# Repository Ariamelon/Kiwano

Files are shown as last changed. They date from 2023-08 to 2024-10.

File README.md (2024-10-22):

# Kiwano
Ring rotary encoder and PMW3360/Cirque [VIK](https://github.com/sadekbaroudi/vik) module with RGB backlight.

## Disclaimer
This board is licensed under CERN-OHL-S-2.0.

## Key Features
* PER56 rotary ring encoder.
* Illuminated RGB ring.
* Cirque trackpad support in the middle of the PER56.
* PMW3360 and 34mm trackball support in the middle of the PER56, utilizing 7.5mm BTUs (e.g. Veichu VCN310 7.5mm).
* Trackball has two styles: illuminated outer ring, and illuminated trackball.

## VIK module certification card

| Category | Classification | Response |
| --- | --- | --- |
| FPC connector | Required | :heavy_check_mark: |
| Breakout pins | Recommended | :x: |
| Uses: SPI | Optional | :heavy_check_mark: |
| SPI used for SPI only | Strongly recommended | :heavy_check_mark: |
| Uses: I2C | Optional | :heavy_check_mark: |
| I2C used for I2C only | Strongly Recommended | :heavy_check_mark: |
| I2C pull ups | Required | :heavy_check_mark: |
| Uses: RGB | Optional | :heavy_check_mark: |
| Uses: Extra GPIO 1 | Optional | :heavy_check_mark: |
| Uses: Extra GPIO 2 | Optional | :heavy_check_mark: |
| Standard PCB Size/Mount | Strongly Recommended | Large |

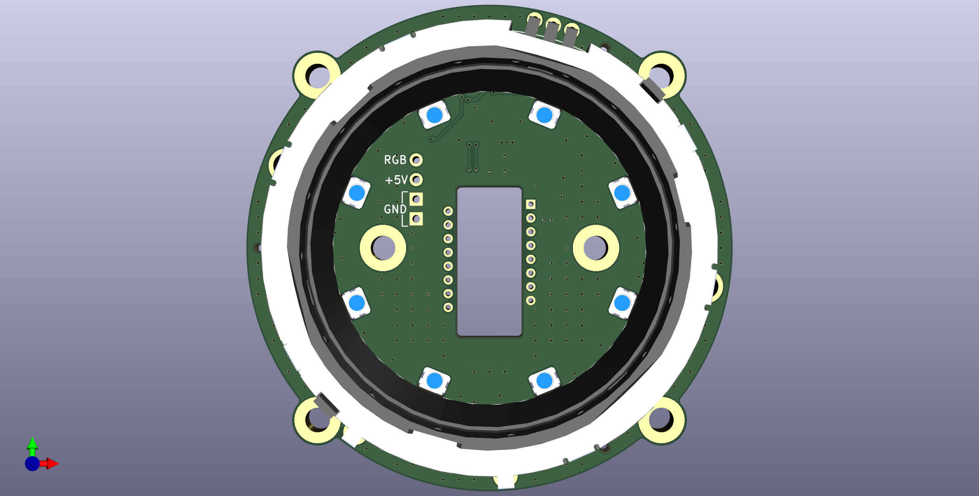
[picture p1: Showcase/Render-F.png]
Render

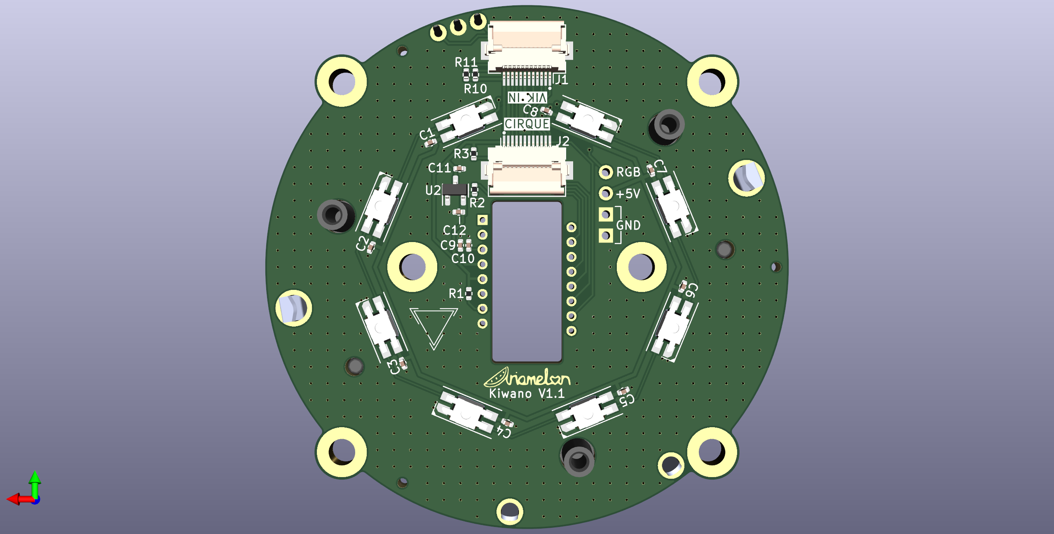
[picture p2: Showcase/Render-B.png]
Render


## Changelog
* 22/10/2024: CERN-OHL-S-2.0 license added.
* 14/10/2023: V1.1 update. Changed LDO to XC6206P202MR. Removed RC filter and pullup from encoder pins.
* 18/09/2023: Fixed .gitignore file. Increased tolerances of PER-56 base mount.
* 28/08/2023: Unified component libraries into one big library. Fixed 3DP files.
* 04/08/2023: Updated SK6812 MINI-E and switch footprints. Changed VIK FFC to FH12. Stitched ground planes together. Fixed VIK footprint. Moved production files to easier to access location.
* 02/08/2023: Fixed 3DP files.
* 01/08/2023: Files for trackpad mount and knob moved here from [Honeydew](https://github.com/Ariamelon/Honeydew/). Added trackball mount STEP files, using 7.5mm BTUs.
* 30/07/2023: Updated BOM.
* 29/07/2023: Added VIK size row to certification card.
* 28/07/2023: Initial commit.

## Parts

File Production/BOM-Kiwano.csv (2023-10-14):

Comment | Designator | Footprint | LCSC
4u7 | C11,C12,C9 | C_0402_1005Metric | C23733
39 | R2 | R_0402_1005Metric | C25164
10k | R1,R3 | R_0402_1005Metric | C25744
4k7 | R10,R11 | R_0402_1005Metric | C25900
XC6206P202MR | U2 | SOT-23-3 | C2891260
100n | C1,C10,C2,C3,C4,C5,C6,C7,C8 | C_0402_1005Metric | C307331
PER56 | SW1 | RotaryEncoder_Bourns_PER561-P115-N0015 | C470483
SK6812MINI-E | D1,D2,D3,D4,D5,D6,D7,D8 | LED_OPSCO_SK6812MINI-E | C524051
VIK Module | J1,J2 | VIK_Module_Horizontal | C88360
PMW3360DM-T2QU_1 | U1 | PixArt_PMW3360DM-T2QU

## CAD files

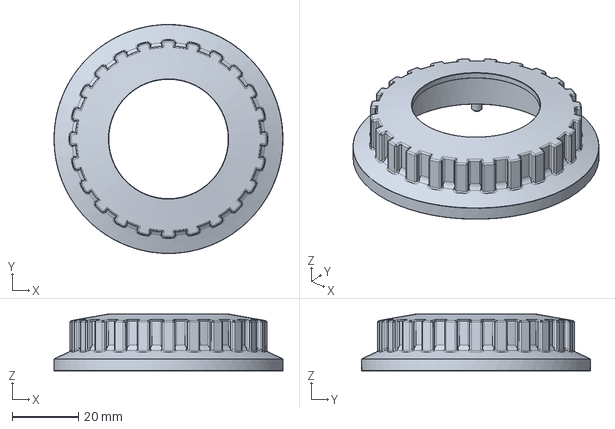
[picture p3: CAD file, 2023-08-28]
3DP/Knob Full.step
69.0 x 69.0 x 17.2 mm

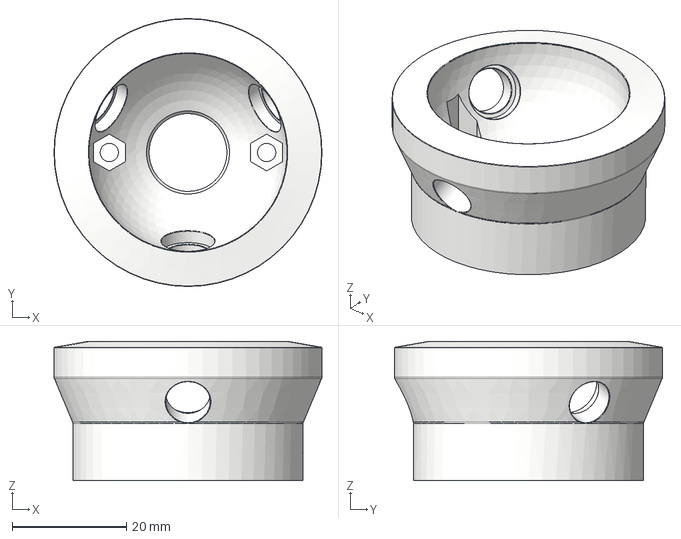
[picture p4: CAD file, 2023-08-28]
3DP/Trackball Mount Full.step
47.0 x 47.0 x 24.4 mm

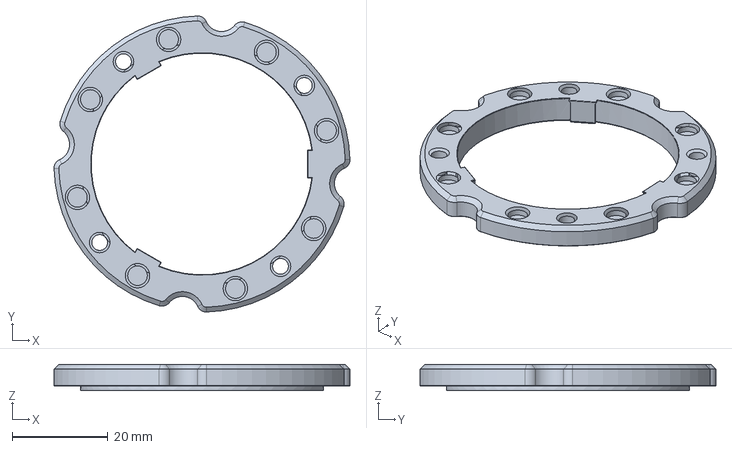
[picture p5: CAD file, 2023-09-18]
3DP/Knob Base.step
62.0 x 62.0 x 5.49 mm

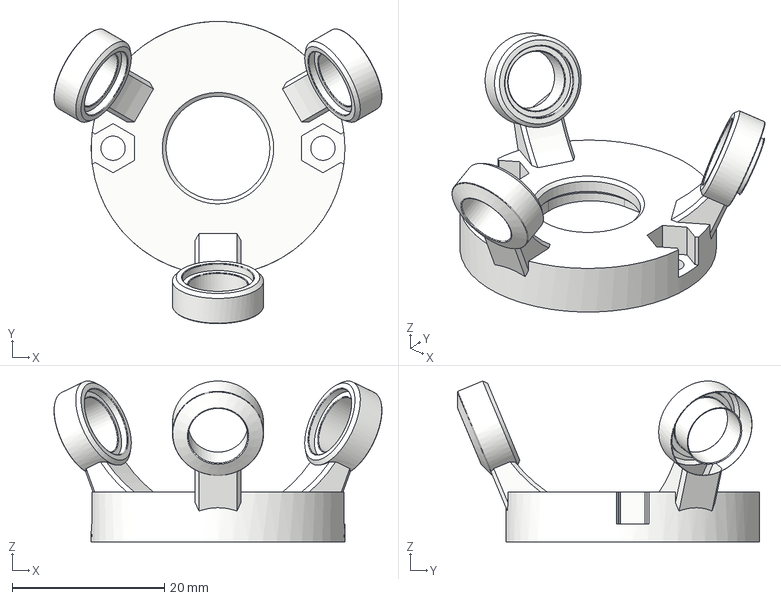
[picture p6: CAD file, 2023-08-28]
3DP/Trackball Mount Low Profile.step
43.1 x 39.7 x 21.2 mm

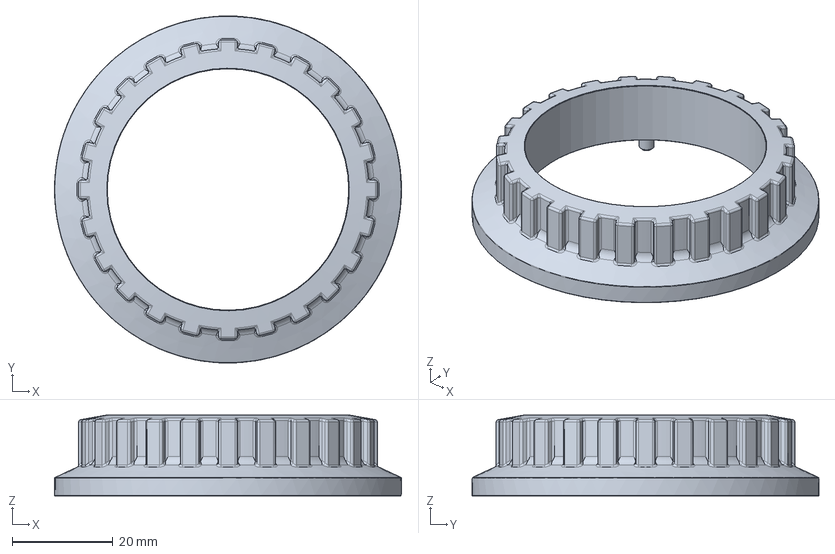
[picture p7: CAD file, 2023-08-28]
3DP/Knob Low Profile.step
69.0 x 69.0 x 16.1 mm

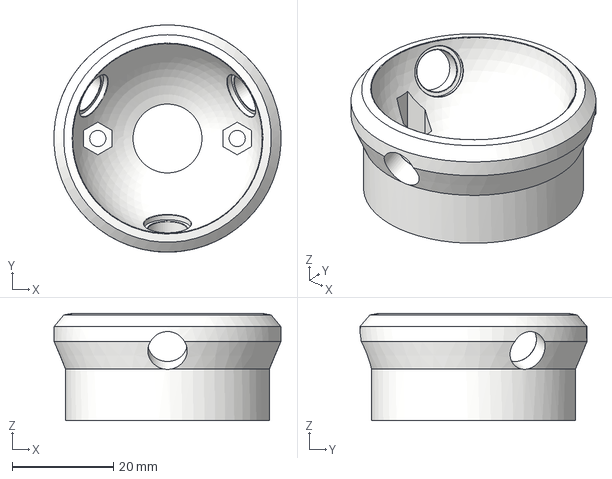
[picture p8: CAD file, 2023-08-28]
3DP/Trackball Mount Semi.step
44.9 x 45.0 x 21.2 mm

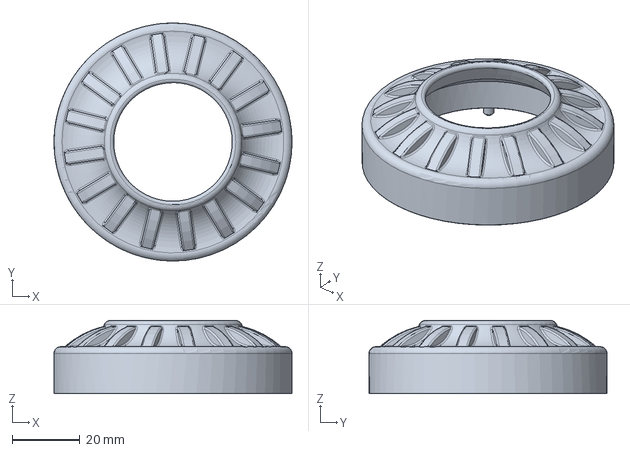
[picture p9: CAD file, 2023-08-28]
3DP/Knob Ribbed.step
70.0 x 70.0 x 21.5 mm

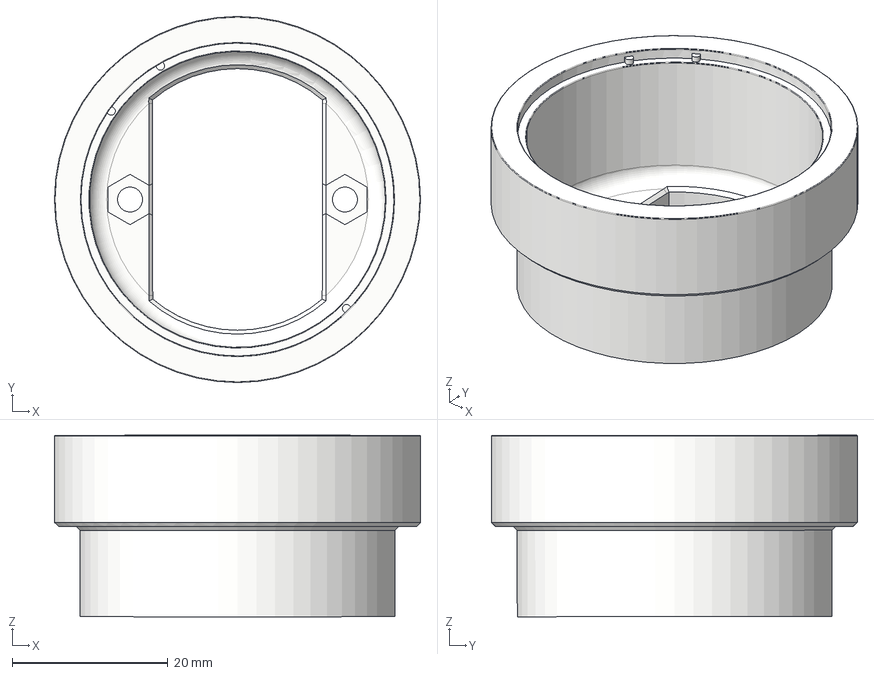
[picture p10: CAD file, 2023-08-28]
3DP/Trackpad Mount.step
47.0 x 47.0 x 23.3 mm

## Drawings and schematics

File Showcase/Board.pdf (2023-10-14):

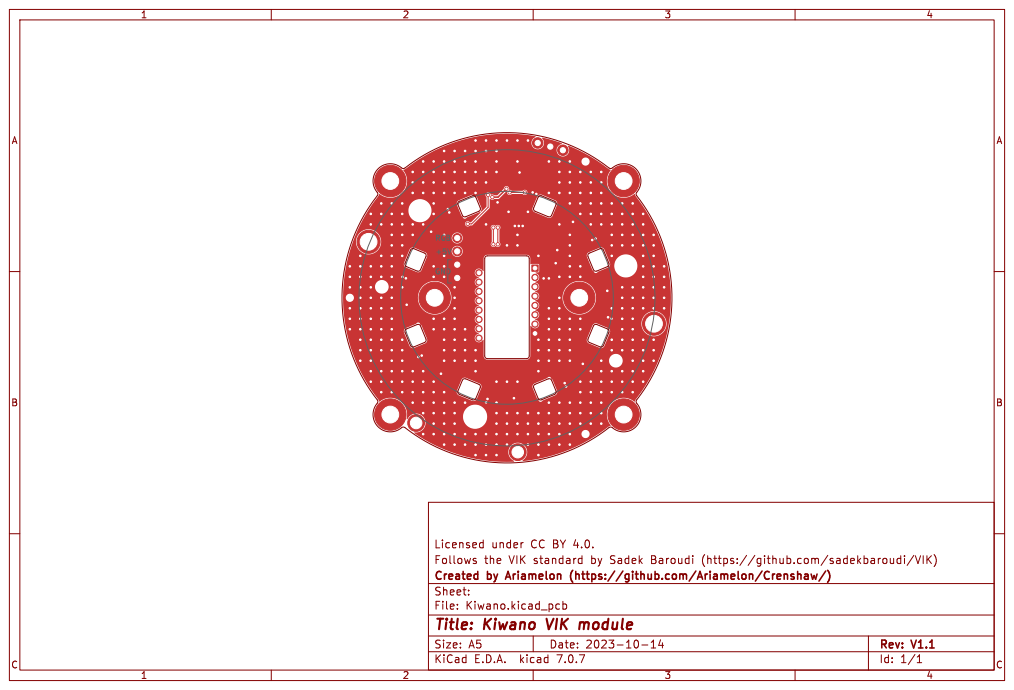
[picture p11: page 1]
GND; +5V RGB 1; BC Date: 2023-10-14 KiCad; kicad; 7.0.7 Size: A5; Rev: V1.1; File:; Kiwano.kicad_pcb Sheet: Created; by Ariamelon; (https://github.com/Ariamelon/Crenshaw/) Follows the VIK standard; by Sadek; Baroudi; (https://github.com/sadekbaroudi/VIK) Licensed; under CC

Id: 1/1 Title: Kiwano VIK module

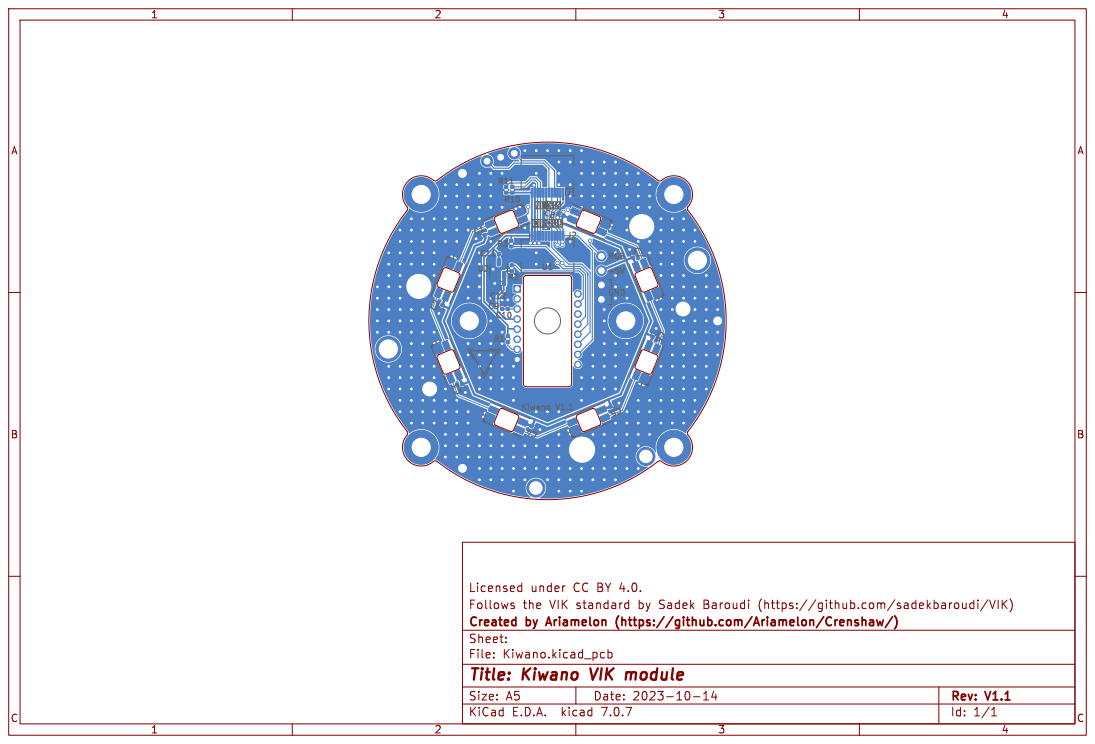
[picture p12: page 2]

Id: 1/1 Title: Kiwano VIK module

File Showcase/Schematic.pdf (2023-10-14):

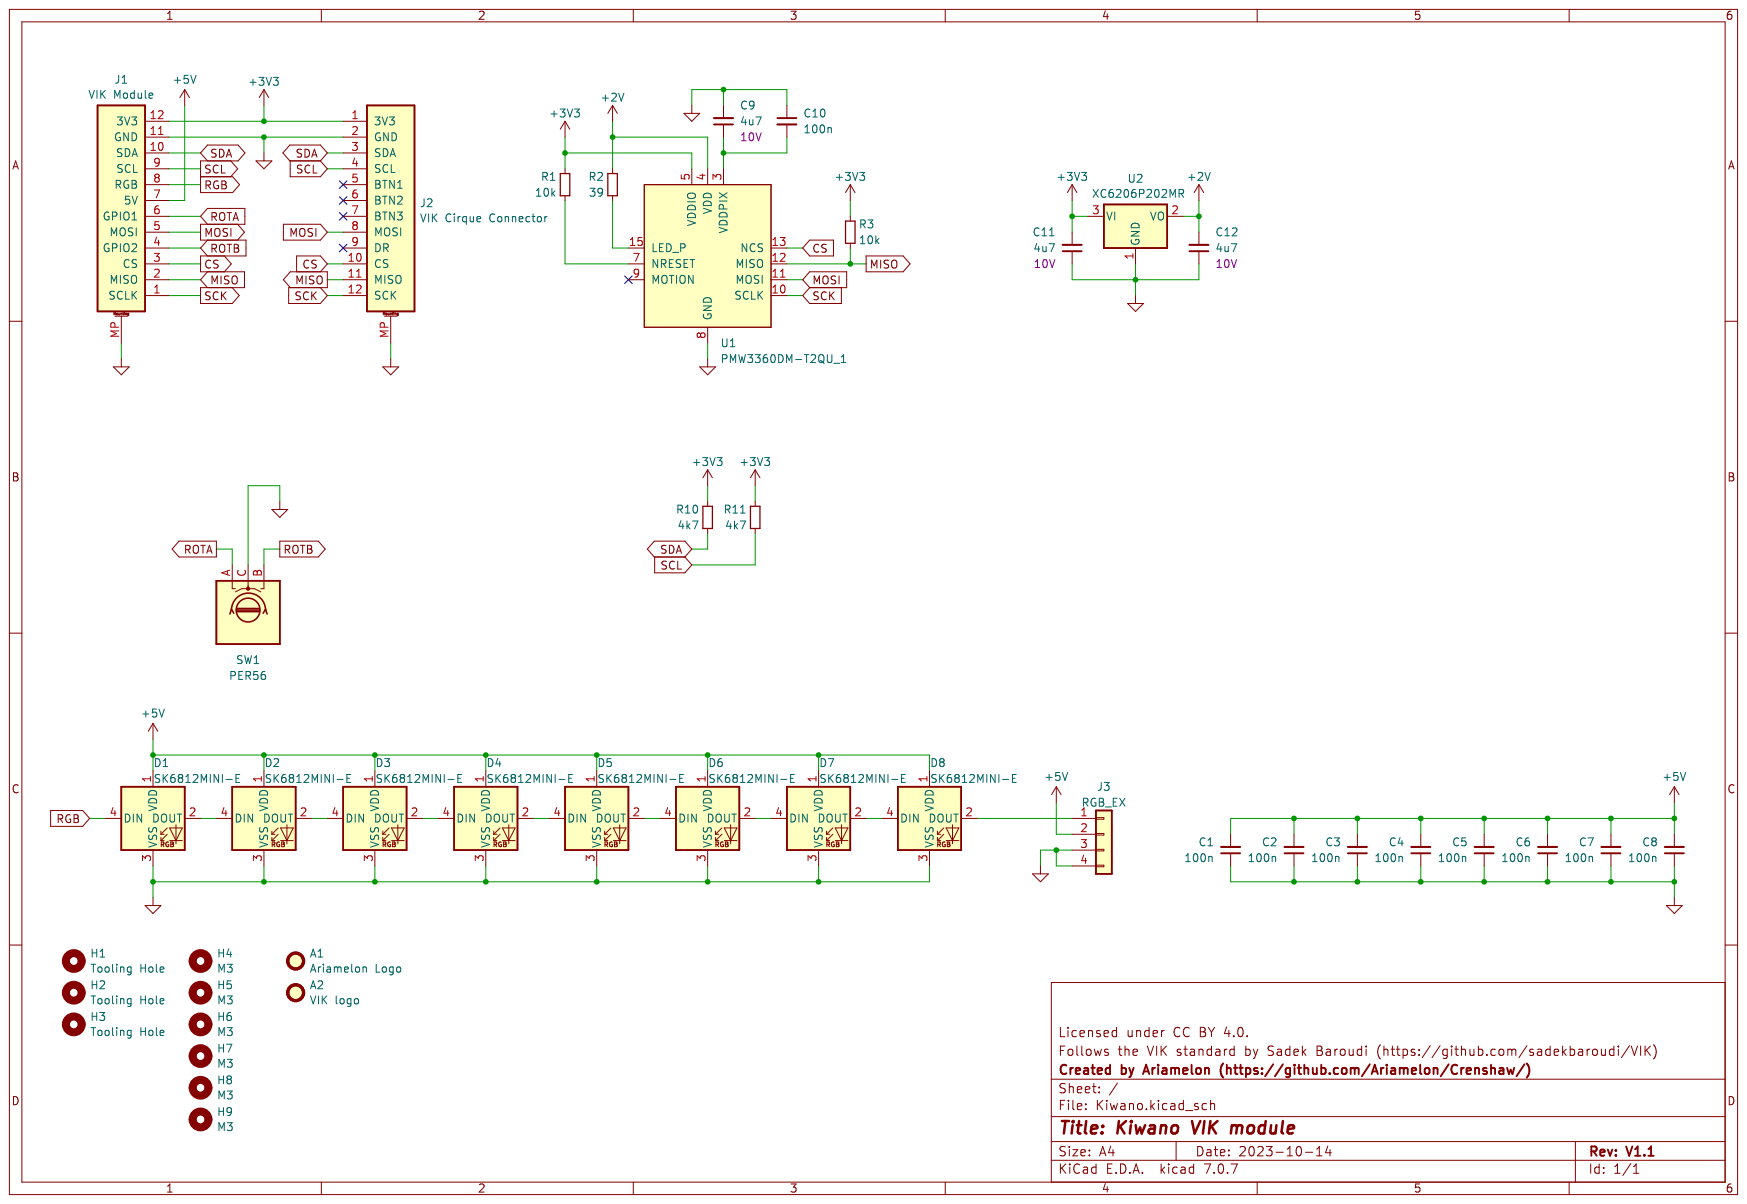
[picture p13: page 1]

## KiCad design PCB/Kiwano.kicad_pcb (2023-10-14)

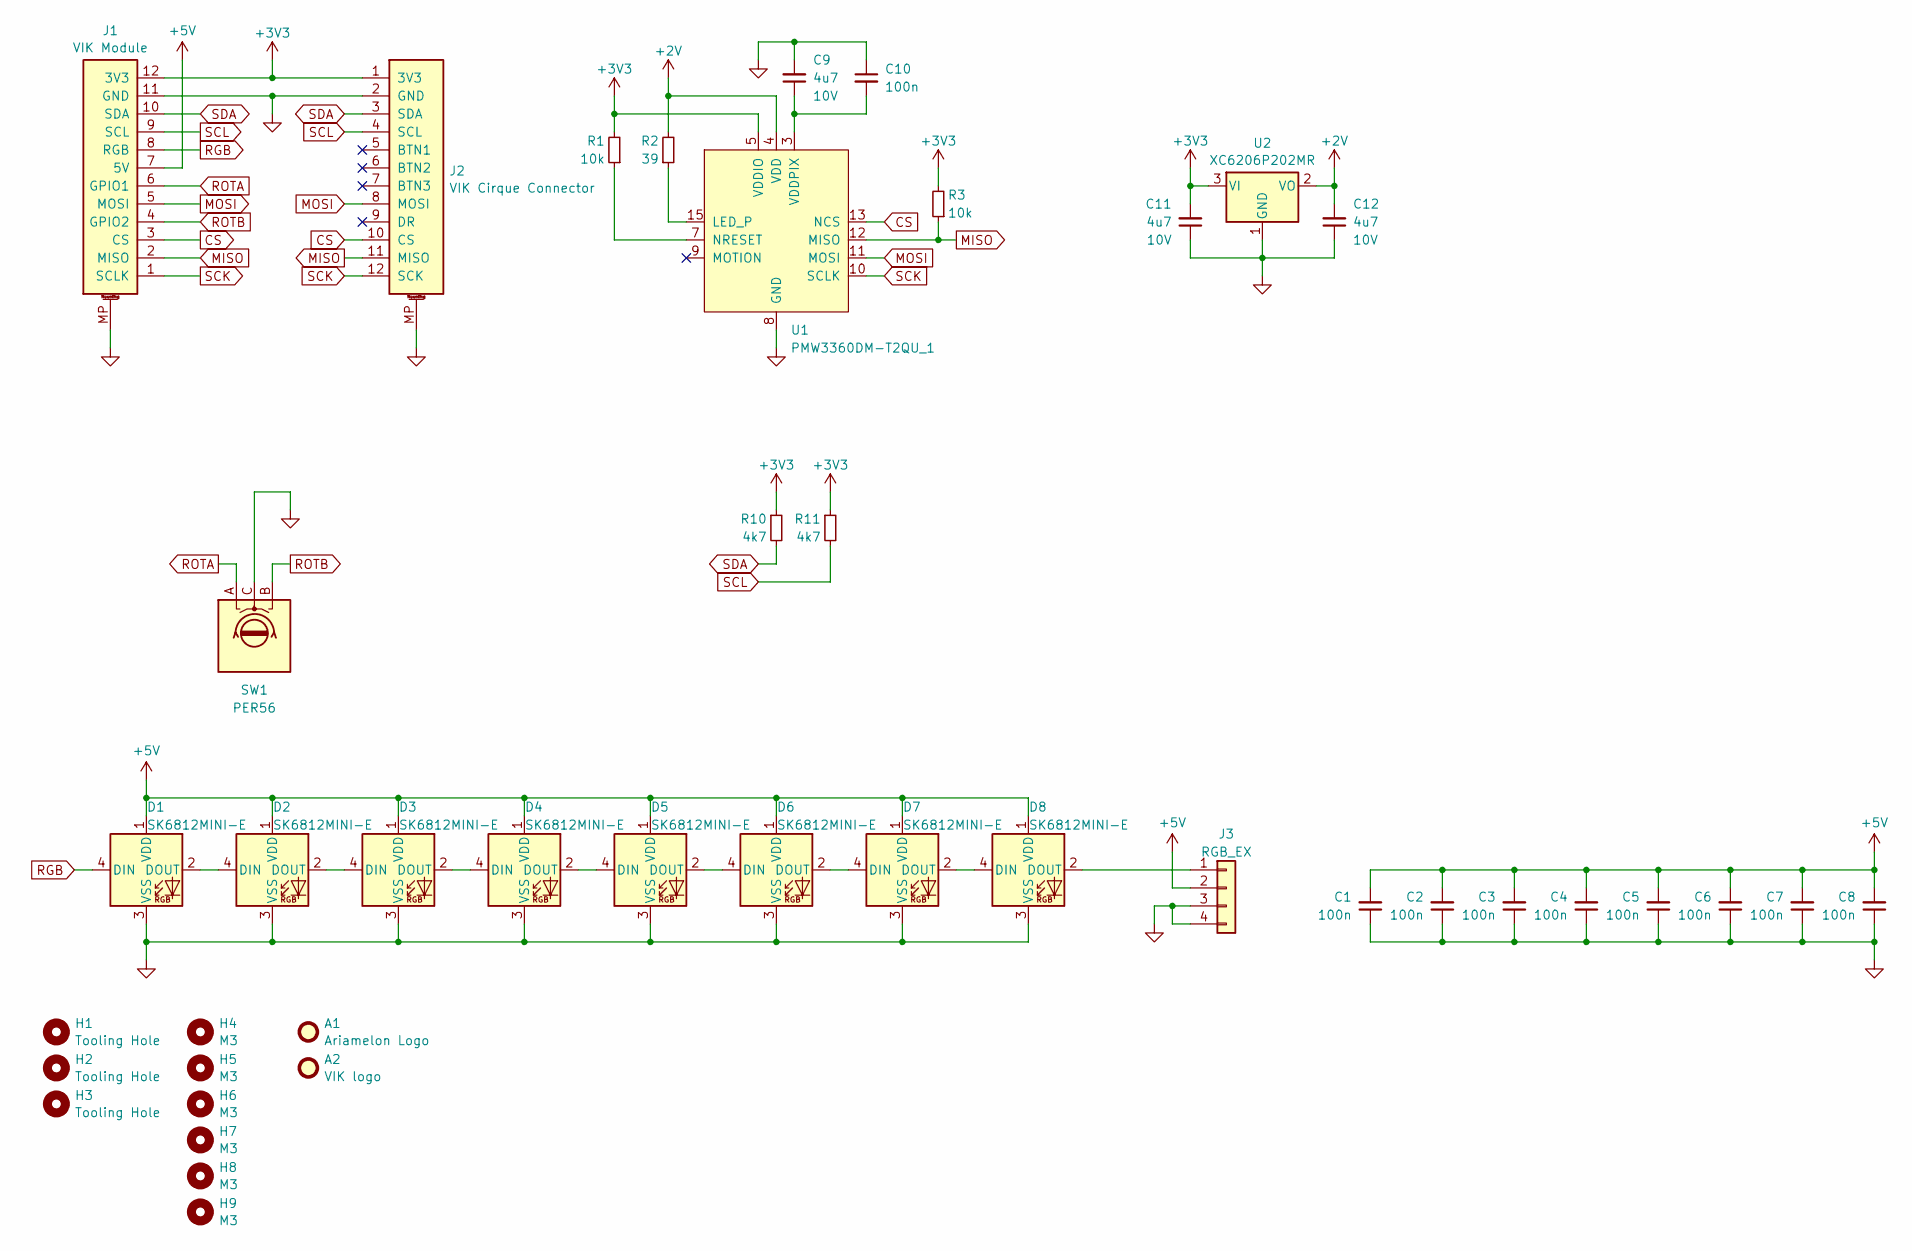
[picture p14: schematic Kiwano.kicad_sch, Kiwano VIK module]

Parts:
A1: Ariamelon Logo; Ariamelon_Logo_Small_Mask
A2: VIK logo; VIK_Logo_Small
C1, C2, C3, C4, C5, C6, C7, C8, C10: 100n; C_0402_1005Metric; Voltage 50V; LCSC C307331
C9, C11, C12: 4u7; C_0402_1005Metric; Voltage 10V; LCSC C23733
D1, D2, D3, D4, D5, D6, D7, D8: SK6812MINI-E; LED_OPSCO_SK6812MINI-E; LCSC C524051
H1, H2, H3: Tooling Hole; MountingHole_JLC-Tooling
H4, H5, H6, H7, H8, H9: M3; MountingHole_3.2mm_M3_Pad
J1: VIK Module; VIK_Module_Horizontal; LCSC C88360
J2: VIK Cirque Connector; VIK_Cirque_Horizontal; LCSC C88360
J3: RGB_EX; PinHeader_RGB
R1, R3: 10k; R_0402_1005Metric; LCSC C25744
R2: 39; R_0402_1005Metric; LCSC C25164
R10, R11: 4k7; R_0402_1005Metric; LCSC C25900
SW1: PER56; RotaryEncoder_Bourns_PER561-P115-N0015; LCSC C470483
U1: PMW3360DM-T2QU_1; PixArt_PMW3360DM-T2QU
U2: XC6206P202MR; SOT-23-3; LCSC C2891260

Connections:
+2V: C12.2, R2.2, U1.4 (VDD), U2.2 (VO)
+3V3: C11.2, J1.12 (3V3), J2.1 (3V3), R1.2, R3.2, R10.1, R11.1, U1.5 (VDDIO), U2.3 (VI)
+5V: C1.2, C2.2, C3.2, C4.2, C5.2, C6.2, C7.2, C8.2, D1.1 (VDD), D2.1 (VDD), D3.1 (VDD), D4.1 (VDD), D5.1 (VDD), D6.1 (VDD), D7.1 (VDD), D8.1 (VDD), J1.7 (5V), J3.2
CS: J1.3 (CS), J2.10 (CS), U1.13 (NCS)
GND: C1.1, C2.1, C3.1, C4.1, C5.1, C6.1, C7.1, C8.1, C9.2, C10.1, C11.1, C12.1, D1.3 (VSS), D2.3 (VSS), D3.3 (VSS), D4.3 (VSS), D5.3 (VSS), D6.3 (VSS), D7.3 (VSS), D8.3 (VSS), J1.11 (GND), J1.MP, J2.2 (GND), J2.MP, J3.3, J3.4, SW1.C, U1.8 (GND), U2.1 (GND)
MISO: J1.2 (MISO), J2.11 (MISO), R3.1, U1.12 (MISO)
MOSI: J1.5 (MOSI), J2.8 (MOSI), U1.11 (MOSI)
unnamed: D1.2 (DOUT), D2.4 (DIN)
unnamed: D2.2 (DOUT), D3.4 (DIN)
unnamed: D3.2 (DOUT), D4.4 (DIN)
unnamed: D4.2 (DOUT), D5.4 (DIN)
unnamed: D5.2 (DOUT), D6.4 (DIN)
unnamed: D6.2 (DOUT), D7.4 (DIN)
unnamed: D7.2 (DOUT), D8.4 (DIN)
unnamed: D8.2 (DOUT), J3.1
unnamed: R2.1, U1.15 (LED_P)
unnamed: R1.1, U1.7 (NRESET)
unnamed: C9.1, C10.2, U1.3 (VDDPIX)
RGB: D1.4 (DIN), J1.8 (RGB)
ROTA: J1.6 (GPIO1), SW1.A
ROTB: J1.4 (GPIO2), SW1.B
SCK: J1.1 (SCLK), J2.12 (SCK), U1.10 (SCLK)
SCL: J1.9 (SCL), J2.4 (SCL), R11.2
SDA: J1.10 (SDA), J2.3 (SDA), R10.2

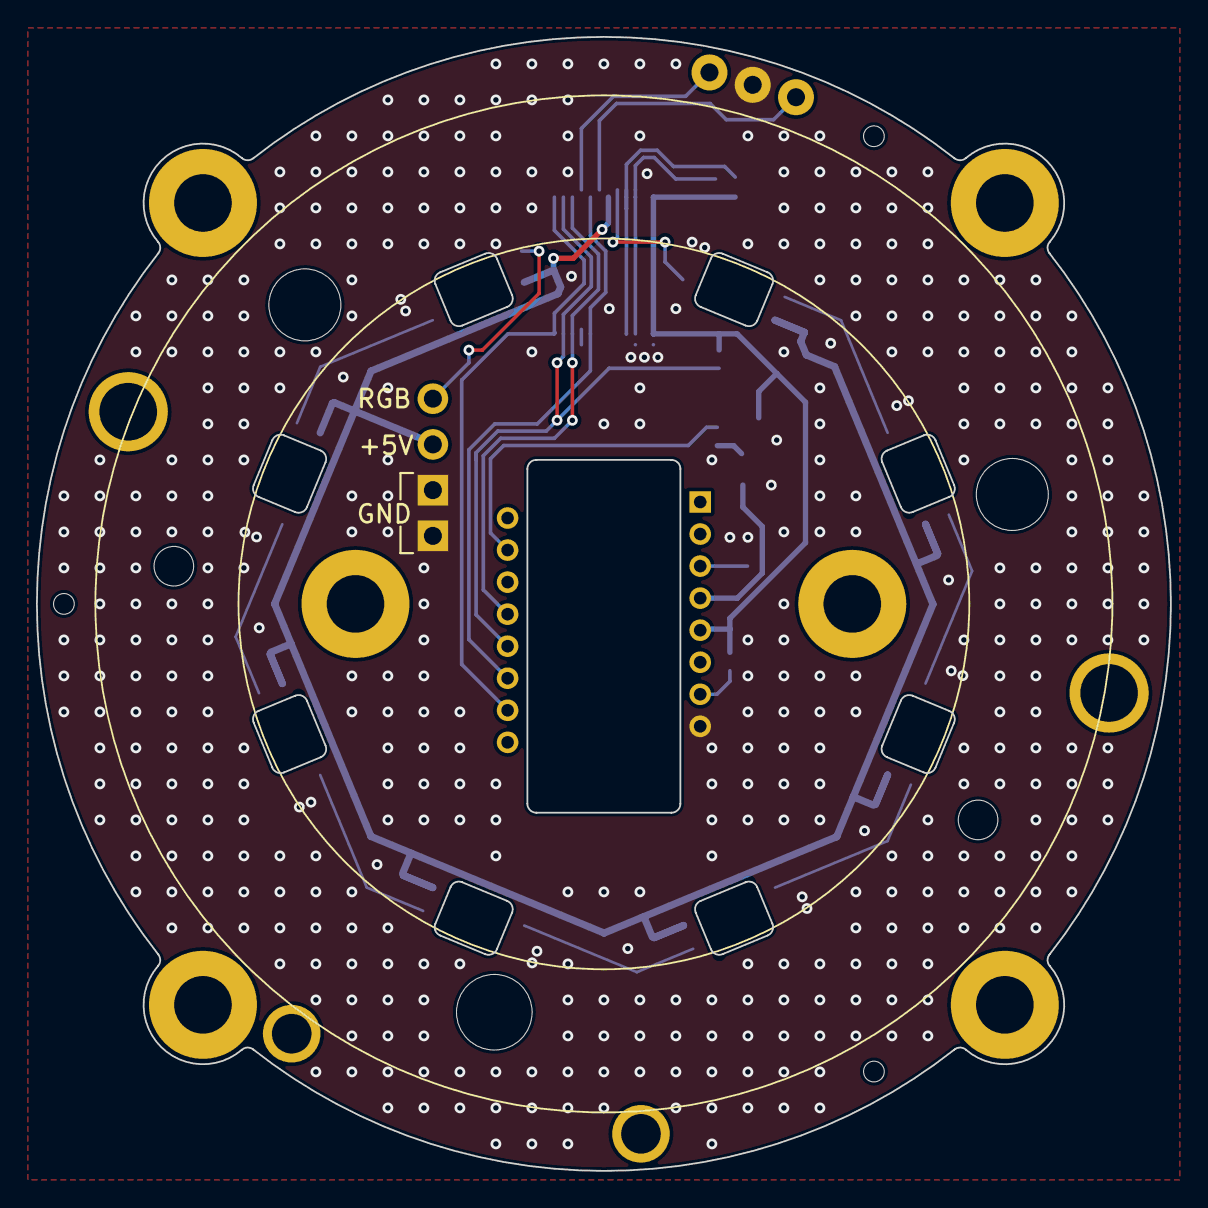
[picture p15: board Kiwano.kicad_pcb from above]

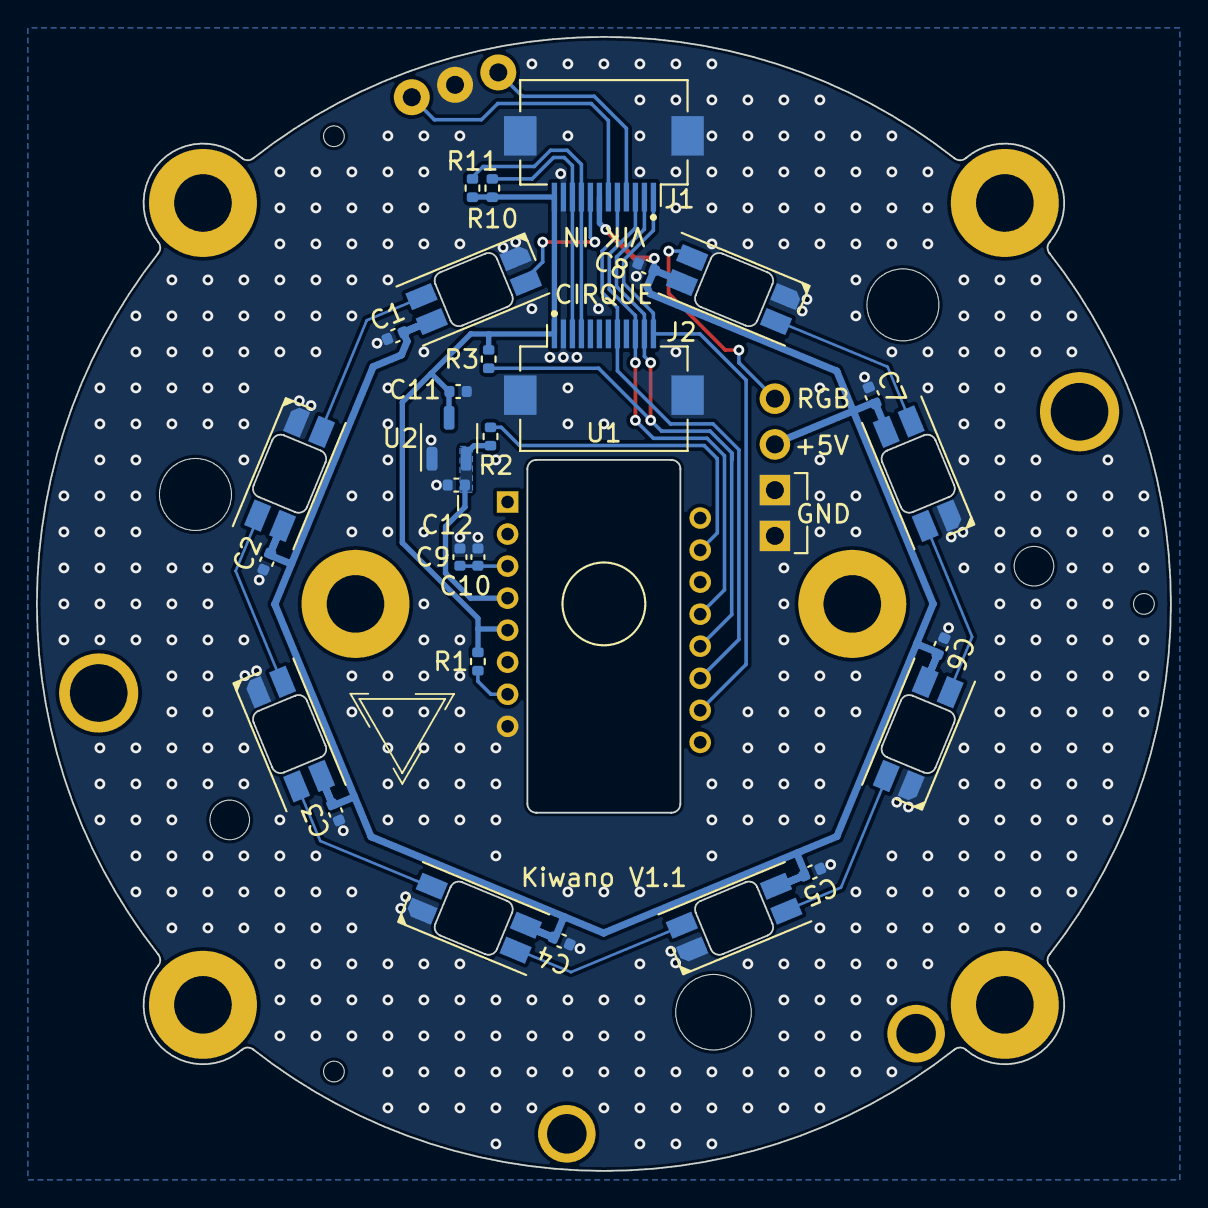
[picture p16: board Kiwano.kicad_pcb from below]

Board: 2 copper layers, 63.0 x 63.0 mm, 42 parts (33 on the bottom side), 24 nets.

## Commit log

2023-07-30 30/07/2023 update
    Updated BOM.
    [Kiwano-CuBottom.gbr, Kiwano-CuTop.gbr, Kiwano-EdgeCuts.gbr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]
2023-08-01 Fixed silk, moved production files.
    [Kiwano-CuBottom.gbr, Kiwano-CuTop.gbr, Kiwano-EdgeCuts.gbr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]
2023-08-01 01/08/2023 update
    Files for trackpad mount and knob moved here from Honeydew. Added trackball mount STEP files, using 7.5mm BTUs.
    [Knob Full.step, Knob Low Profile.step, Trackball Mount Full.step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]
2023-08-02 02/08/2023 update
    Fixed 3DP files.
    [Knob Base.step, Knob Full.step, Knob Low Profile.step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]
2023-08-04 04/08/2023 update
    Updated SK6812 MINI-E and switch footprints. Changed VIK FFC to FH12. Stitched ground planes together. Fixed VIK footprint. Moved production files to easier to access location.
    [Kiwano.kicad_pcb, Kiwano.kicad_sch]
2023-08-28 28/08/2023 update
    Unified component libraries into one big library. Fixed 3DP files.
    [Kiwano.kicad_pcb, Kiwano.kicad_sch, Knob Base 1.step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]
2023-09-18 18/09/2023 update
    Fixed .gitignore file.
    [BOM-Kiwano.csv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]
2023-09-18 18/09/2023 update
    Fixed .gitignore file. Increased tolerances of PER-56 base mount.
    [BOM-Kiwano.csv, Knob Base 1.step, Knob Base 2.step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]
2023-10-14 V1.1 update
    Changed LDO to XC6206P202MR. Removed RC filter and pullup from encoder pins.
    [BOM-Kiwano.csv, Kiwano.kicad_pcb, Kiwano.kicad_sch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]

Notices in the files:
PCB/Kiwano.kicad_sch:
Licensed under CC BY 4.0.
